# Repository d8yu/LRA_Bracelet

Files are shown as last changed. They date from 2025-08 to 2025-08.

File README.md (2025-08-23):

<h1>BEAR LRA Bracelet</h1>
<h2>What is it?</h2>
As part of the BEAR lab at UC Davis, I've designed a prototype for a bracelet that will be used in future experiments to enhance pediatric prosthetics embodiment and control by using vibratory stimulation of muscle to induce illusory movement.

In this repo, you will find the associated code and 3D print files.

<h2>Preview</h2>
Preview
3D Model for Bracelet

<h2>Installation and Configuration</h2>

To install and configure the bracelet, download all src files and place them in an accesible folder. 

Open the .ino src file into the Arduino IDE and upload to the board after configuring the hardware as described in the [hardware_configuration](configuration_instructions/hardware_configuration.txt) file and the software as described in the [software_configuration](configuration_instructions/software_configuration.txt) file

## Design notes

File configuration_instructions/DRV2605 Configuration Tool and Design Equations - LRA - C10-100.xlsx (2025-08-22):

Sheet: Initialize
Selective Disclosure
DRV2605 Initialization Sequence
Register |  |  | Parameter Selection
Name | Addr | Value (Hex) | Name | Bits | Setting | Description
Rated Voltage | 0x16 | 53 | RatedVoltage | [7:0] | Write hex value in C6 | Calculate using ERM/LRA Voltage Worksheet
Overdrive Clamp Voltage | 0x17 | 89 | ODClamp | [7:0] | Write hex value in C7 | Calculate using ERM/LRA Voltage Worksheet
Feedback Control | 0x1A | B7 | nERM_LRA | [7] | 1 - LRA | Set ERM or LRA Mode
 |  |  | FBBrakeFactor | [6:4] | 3 - 4x (default) | Ratio of brake gain to drive gain
 |  |  | Loop Response | [3:2] | 1 - Medium (default) | Loop gain for feedback control
 |  |  | BEMFGain | [1:0] | 3 - 4.0x / 30x | Analog gain of BEMF amplifier, obtained from auto-calibration
Auto-calibration Compensation Results | 0x18 | 06 | ACalComp | [7:0] | Write value obtained from auto-calibration | Voltage compensation
Auto-calibration Back-EMF Result | 0x19 | ED | ACalBEMF | [7:0] | Write value obtained from auto-calibration | Contains the rated back-EMF compensation
Control 1 | 0x1B | 93 | StartupBoost | [7] | 1 - ON (default) | Overdrive boost
 |  |  | AC_Couple | [5] | 0 - DC Coupling / Digital Input Modes (default) | PWM/TRIG Pin Coupling Setting
 |  |  | DriveTime | [4:0] | 19 | Initial LRA drive time (Default = 19) Drive Time[4:0] = (Drive Time (ms) - 0.5ms) / 0.1
Control 2 | 0x1C | EA | BiDir_Input | [7] | 1 - Bi-directional (default) | Select input scaling for input
 |  |  | Brake_Stabilizer | [6] | 1 - ON (default) | Reduce loop gain when braking is near completion
 |  |  | SampleTime | [5:4] | 2 - 250 µs | LRA Auto-Resonance Detection
 |  |  | Blanking Time | [3:2] | 2 - 50 µs, 150 µs | Blanking time before back-EMF conversion
 |  |  | IDissTime | [1:0] | 2 - 50 µs, 150 µs | Current Dissipation Time
Control 3 | 0x1D | 80 | NG_Thresh | [7:6] | 2 - 4% (default) | Noise gate threshold for PWM and analog inputs
 |  |  | ERM_OpenLoop | [5] | 0 - Closed Loop (default) | Select ERM open-loop or closed-loop
 |  |  | SupplyCompDis | [4] | 0 - ON (default) | Disable supply compensation
 |  |  | DataFormat_RTP | [3] | 0 - Signed (default) | Select binary input coding for RTP
 |  |  | LRA DriveMode | [2] | 0 - Once per cycle (default) | Select drive mode for LRA algorithm
 |  |  | nPWM_Analog | [1] | 0 - PWM Input (default) | Select input mode for IN/TRIG pin (Mode 3)
 |  |  | LRA_OpenLoop | [0] | 0 - Auto Resonance On (default) | Enable/Disable Auto-resonance
Library Selection | 0x03 | 06 | HiZ | [4] | 0 - OFF (default) | Set output pins to Hi-Z
 |  |  | LibrarySel | [2:0] | 6 - LRA Library | Select waveform library
Mode | 0x01 | 40 | Dev_Reset | [7] | 0 - OFF (default) | Reset device registers
 |  |  | STANDBY | [6] | 1 - Device in Software Standby (default) | Enter/Exit Hardware Standby Mode
 |  |  | Mode | [2:0] | 0 - Internal Trigger (default) | Select input mode

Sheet: Play Waveform
Selective Disclosure
DRV2605 Play Waveform Sequence
Register |  |  | Parameter Selection
Name | Addr | Value (Hex) | Name | Bits | Setting | Description
Mode | 0x01 | 00 | Dev_Reset | [7] | 0 - OFF (default) | Reset device registers
 |  |  | STANDBY | [6] | 0 - Device Ready | Enter/Exit Hardware Standby Mode
 |  |  | Mode | [2:0] | 0 - Internal Trigger (default) | Select input mode
Waveform Sequencer | 0x04 | -- | Wait + WavfrmSeq1 | [7:0] | Write waveform identifier or wait time | WavfrmSeq holds the waveform indentifier of the waveform to be played. A waveform identifier is an integer value referring to the index position of a waveform in a ROM library. When bit [7] is set, bits WavfrmSeq[6:0] become a wait time with 10ms units. Delay (ms) = WavfrmSeq[6:0] * 10ms
 | 0x05 | -- | Wait + WavfrmSeq2 | [7:0]
 | 0x06 | -- | Wait + WavfrmSeq3 | [7:0]
 | 0x07 | -- | Wait + WavfrmSeq4 | [7:0]
 | 0x08 | -- | Wait + WavfrmSeq5 | [7:0]
 | 0x09 | -- | Wait + WavfrmSeq6 | [7:0]
 | 0x0A | -- | Wait + WavfrmSeq7 | [7:0]
 | 0x0B | -- | Wait + WavfrmSeq8 | [7:0]
GO | 0x0C | 01 | GO | [0] | 1 - ON | Set GO bit to begin Auto-Calibration
Status | 0x00 | Read (0x60) | DeviceID | [7:5] | Read - 011 | Device identifier
 |  |  | Diag_Result | [3] | Read - 0 | Set to zero when not in auto-calibration
 |  |  | Watchdog_status | [2] | Read - 0 / 1 | Feedback controller status
 |  |  | OverTemp | [1] | Read - 0 | Over-temperature Flag
 |  |  | OC_Detect | [0] | Read - 0 | Over-current Flag

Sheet: Audio-to-Haptics
Selective Disclosure
DRV2605 Audio-to-Haptics (ATH) Configuration
Audio-to-haptics converts an analog audio signal to a haptics output waveform for either ERM or LRA actuators. To setup the DRV2605 for audio-to-haptics, the maximum input voltage of the audio source should be 1.8Vpp (Full Scale). If it is over 1.8Vpp we recommend you use a resistor divider to reduce the input voltage. If the voltage is under 1.8Vpp then you can adjust the full-scale input voltage setting of the DRV2605 using the Maximum Input Detection Register (ATH_MaxInput 0x13).
Begin by enter the the voltage settings in the diagram below.
Maximum Input Voltage - ATH_MaxInput (0x13) |  |  |  |  |  | Maximum Output Drive (%) - ATH_MaxDrive (Reg. 0x15)
1.80 V |  |  |  |  |  | 100%
Minimum Input Voltage - ATH_MinInput (0x12) |  |  |  |  |  | Minimum Output Drive (%) - ATH_MinDrive (Reg. 0x14)
0.18 V |  |  |  |  |  | 10%
Audio-to-Haptics Setup Sequence
Register |  |  | Parameter Selection
Name | Addr | Value (Hex) | Name | Bits | Setting | Description
Mode | 0x01 | 04 | Dev_Reset | [7] | 0 - OFF (default) | Exit Standby Mode (EN pin must be high)
 |  |  | STANDBY | [6] | 0 - Device Ready
 |  |  | Mode | [2:0] | 4 - Audio to Haptics
Audio to Haptic Control | 0x11 | 05 | ATH_PeakTime | [3:2] | 1 - 20 ms (default) | Set ATH rectification time for the audio to haptics
 |  |  | ATH_Filter | [1:0] | 1 - 125 Hz (default) | Set theATH low-pass filter frequency
ATH Minimum Input Level | 0x12 | 19 | ATH_MinInput | [7:0] | 0.18 V | Minimum voltage detected on IN/TRIG for ATH
ATH Maximum Input Level | 0x13 | FF | ATH_MaxInput | [7:0] | 1.80 V | Maximum voltage detected on IN/TRIG for ATH
ATH Minimum Output Drive | 0x14 | 19 | ATH_MinDrive | [7:0] | 10% | Set the minimum output level (%) of drive engine
ATH Maximum Output Drive | 0x15 | FF | ATH_MaxDrive | [7:0] | 100% | Set the maximum output level (%) of drive engine
Control 1 | 0x1B | B3 | StartupBoost | [7] | 1 - ON (default) | Overdrive boost
 |  |  | AC_Couple | [5] | 1 - AC Coupling | PWM/TRIG Pin Coupling Setting
 |  |  | DriveTime | [4:0] | 19 | Initial LRA drive time (Default = 19) Drive Time[4:0] = (Drive Time (ms) - 0.5ms) / 0.1
Control 3 | 0x1D | 82 | NG_Thresh | [7:6] | 2 - 4% (default) | Noise gate threshold for PWM and analog inputs
 |  |  | ERM_OpenLoop | [5] | 0 - Closed Loop (default) | Select ERM open-loop or closed-loop
 |  |  | SupplyCompDis | [4] | 0 - ON (default) | Disable supply compensation
 |  |  | DataFormat_RTP | [3] | 0 - Signed (default) | Select binary input coding for RTP
 |  |  | LRA DriveMode | [2] | 0 - Once per cycle (default) | Select drive mode for LRA algorithm
 |  |  | nPWM_Analog | [1] | 1 - Analog Input | Select input mode for IN/TRIG pin (Mode 3)
 |  |  | LRA_OpenLoop | [0] | 0 - Auto Resonance On (default) | Enable/Disable Auto-resonance
Mode | 0x01 | 03 | Dev_Reset | [7] | 0 - OFF (default) | Enable Audio-to-Haptics
 |  |  | STANDBY | [6] | 0 - Device Ready
 |  |  | Mode | [2:0] | 4 - Audio to Haptics

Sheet: LRA Voltage Equations
DRV2604/5 Design Equations for LRA |  |  |  |  |  |  |  | 12/6/2012
Input |  |  | Calculation
Actuator Parameters
 |  | 175 | Hz |  |  | 2 | Vrms |  | 3 | Vpeak
Register Settings
 |  |  |  | 300 | us
 |  |  |  | Default = 300 µs
Rated & Overdrive Voltage Summary
 |  |  |  | 83 | (Dec) |  |  |  | 137 | (Dec)
Closed Loop |  |  |  | 53 | (Hex) |  | Closed Loop |  | 89 | (Hex)
 |  |  |  | 01010011 | (Binary) |  |  |  | 10001001 | (Binary)
Rated Voltage (Closed Loop)
 |  |  |  |  |  |  |  |  | 1.72 | V
 |  |  |  |  |  |  |  |  | 83 | (Dec)
 |  |  |  |  |  |  |  |  | 53 | (Hex)
 |  |  |  |  |  |  |  |  | 01010011 | (Binary)
 |  |  |  |  |  |  |  |  |  | Use the RatedVoltage(0x16) value for the DRV2605 RatedVoltage register
Overdrive Voltage (Closed Loop)
 | 3.00 | VDC
 |  |  |  |  |  |  |  |  | 137 | (Dec)
 |  |  |  |  |  |  |  |  | 89 | (Hex)
 |  |  |  |  |  |  |  |  | 10001001 | (Binary)
 |  |  |  |  |  |  |  |  |  | Use the ODClamp(0x17) value for the DRV2605 OverdriveClamp register

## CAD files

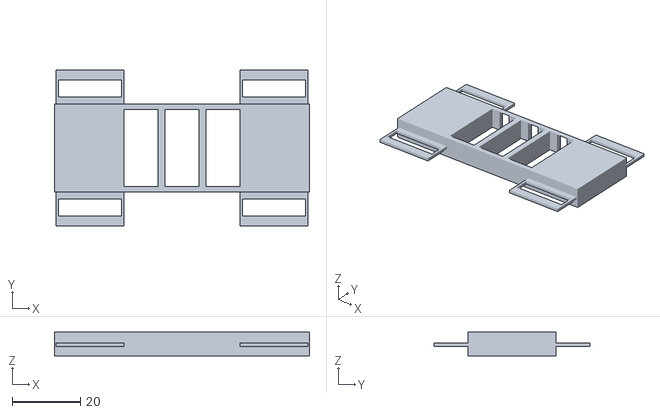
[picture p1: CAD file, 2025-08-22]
Enclosure/Square_Bracelet_V2-Body.stl
75.0 x 46.0 x 7.00

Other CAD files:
Enclosure/Square_Bracelet_V2.FCStd

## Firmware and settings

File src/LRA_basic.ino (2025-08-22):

#include "Haptic_DRV2605.h"
Haptic_DRV2605 haptic;             // Basic I2C instance - only SDA/SCL pins used
int           waveform = 0;        // current waveform
int           waveforms_max = 0;   // max waveforms available (we'll ask...)
int           select_mode = 0; 

//Custom definitions for PCA9548A I2C Data Bus Multiplexer  
#define PCAADDR 0x70      //PCA9548A I2C Data bus multiplexer default address 

//Prototypes 
void PCAselect(uint8_t i);
void switch_LRA();





void setup() {
  Serial.begin(115200);
   while (!Serial) {
    ; // wait for serial port to connect. Needed to see startup messages...
  }

  Serial.println("Haptic: LRA Driver Basic Tests");
  Serial.println("Haptic: Connect I2C pins to WIRE Pins (SDA, SCL)");

  PCAselect(6); //Call PCAselect for device at SD2

  // initialize the Haptic controller
    if (haptic.begin() != HAPTIC_SUCCESS) {
      Serial.println("Haptic: Driver Error: DRV2605L Device not found - check your I2C connections?");
  } else {
      // okay correct chip, let's initialize it
      Serial.println("Haptic: DeviceID = DRV2605L @ Address 0x5A was found! ");
      // config the DRV2605 chip
      haptic.setActuatorType(LRA);              // pick an actuator type
      haptic.setMode(REGISTER_MODE);            // haptic effects triggered by I2C register write 
      waveforms_max = haptic.getWaveforms();    // how many waveforms available?
  }


PCAselect(2);
 if (haptic.begin() != HAPTIC_SUCCESS) {
      Serial.println("Haptic: Driver Error: DRV2605L Device not found - check your I2C connections?");
  } else {
      // okay correct chip, let's initialize it
      Serial.println("Haptic: DeviceID = DRV2605L @ Address 0x5A was found! ");
      // config the DRV2605 chip
      haptic.setActuatorType(LRA);              // pick an actuator type
      haptic.setMode(REGISTER_MODE);            // haptic effects triggered by I2C register write 
      waveforms_max = haptic.getWaveforms();    // how many waveforms available?
  }



}

void loop() {
 
  //Switch between the two LRAs
  switch_LRA();
 
 // loop through all the waveforms
  Serial.print("Waveform #");                   // which waveform
  Serial.println(waveform);
  haptic.setWaveform(0, waveform);              // set the first sequence
  haptic.setWaveform(1, 0);                     // end the sequence
  haptic.goWait();	
 			                      // play the waveform
  delay(100);	
	                          // wait for a while
  waveform++;	
  				                          // next waveform
  if (waveform >= 3) waveform = 0;
}



void switch_LRA(){

   switch(select_mode){

    case 0:
      PCAselect(2);
      select_mode = 1;
      break;

    case 1:
      PCAselect(6);
      select_mode = 0;
      break; 

  }
}



void PCAselect(uint8_t i){

if(i > 7) return;
Wire.beginTransmission(PCAADDR);
Wire.write(1 << i);
Wire.endTransmission();

}

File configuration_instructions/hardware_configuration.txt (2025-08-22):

This document gives a brief summary and overview of the hardware for the BEAR bracelet. 

At the heart of the bracelet is an Arduino MCU. 

From this MCU, we can control our linear resonance actuators (LRAs) by using the library provided in the src

It is only possible to control a singular LRA from the Arduino due to the DRV2605L motor drivers having the same hardcoded i2c address. 

To overcome this issue, we must use an i2c multiplexer to allow the MCU to interact with multiple devices withe same i2c address. 


To connect the LRAs to the Arduino, wire the positive and negative leads (usually marked by red and black) to their respective leads on the DRV2605L motor driver board. 

Next, instead of connecting the SDA and SCL lines from the motor driver boards to the Arduino's SDA and SCL pins-connect the Arduino's pins to the SDA and SCL pins on the PCA9548A i2c multiplexer board. 

You can find the Arduino's i2c lines by consulting the respective board's datasheet. 

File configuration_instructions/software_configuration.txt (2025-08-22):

This document provides an overview for configuring the software for the BEAR bracelet

Once your hardware is configured, you can start configuring your hardware. 

IMPORTANT: In the code, you'll notice the PCAselect() function. In order to actually select the appropriate line on the PCA9548A, pay attention to which number SDx and SCx lines you've connected to your DRV2605L drivers. 
	ex. If you've connected one of your DRV2605L drivers to SC6 and SD6, make sure one of the calls of the PCAselect() function is called as PCAselect(6);

After this, you should be good to simply upload the code and see a successful result. 
